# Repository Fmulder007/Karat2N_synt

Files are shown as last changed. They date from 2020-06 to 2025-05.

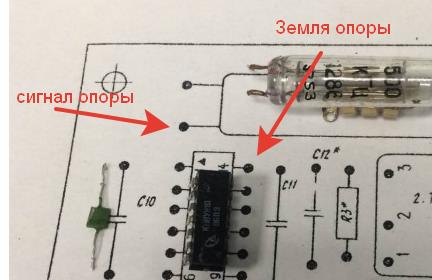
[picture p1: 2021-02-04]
Photo/2021-02-04_23-24-12.jpg

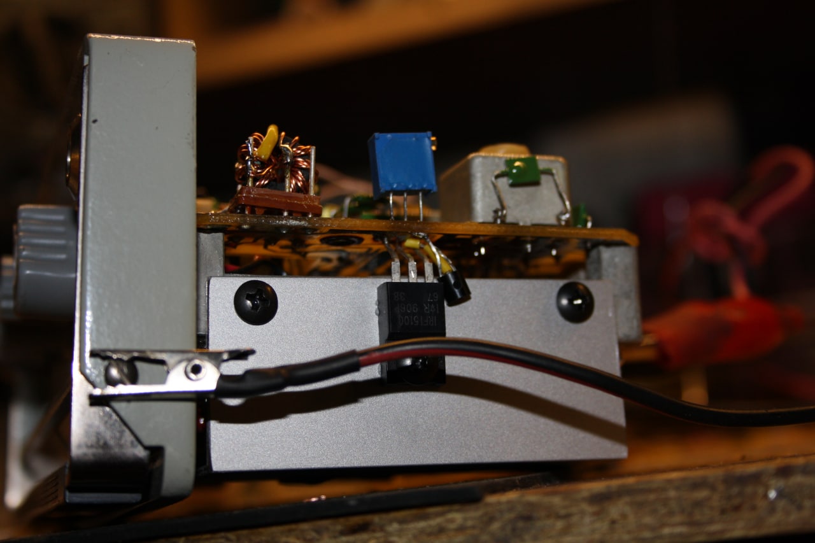
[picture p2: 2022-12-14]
Photo/photo_2022-12-13_17-33-39.jpg

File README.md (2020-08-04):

# Karat2N_synt

Проект модернизации радиостанции Карат-2Н от UD0CAJ.

Функционал:
	Один НЧ любительский диапазон (160,80 или 40 метров)
	
	Шаг настройки 10, 100, 500, 1000 Гц
	
	Нижняя боковая полоса
	
	Синтезатор si5351
	
	Часы DS1307
	
	Память 24C32n
	
	Измерение температуры (датчик DS18B20 имеет тепловой контакт с передней панелью радиостанции)
	
	Сдвиг ПЧ (IF-Shift) на приеме позволяет отстроиться от близкой помехи.
	
	Выходная мощность 2-3 ватта (зависит от диапазона)
	
Видео работы на 40 метрах от Александра Никитенко https://youtu.be/9bqwGd6Wv5c?t=20
Официальный телеграмм канал техподдержки проекта https://t.me/Karat2_sintez
Адрес электронной почты автора fmulder007@yandex.ru

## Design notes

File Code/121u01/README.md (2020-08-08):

# Karat2N_synt
v 121u01
Функционал:
	CLK0 - vfo, CLK1 - lo.
	Один НЧ любительский диапазон (160,80 или 40 метров)
	Шаг настройки 10, 100, 500, 1000 Гц
	Прием=ГПД+ПЧ
	Границы ПЧ от 1 до 25 МГц
	Синтезатор si5351a от UR5FFR
	Часы DS1307 
	Память 24C32n используется для хранения данных
	датчик DS18B20
	Сдвиг ПЧ (IF-Shift) на приеме позволяет отстроиться от близкой помехи.

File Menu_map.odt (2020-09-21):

# Шпаргалка

Радиостанция Карат-2Н

Переделка UD0CAJ

Меню

Меню управления состит из 10 пунктов, которые нумеруются от 0 до 9. Меню разделено на две части: основное меню и инженерное меню. Переход по пунктам внутри каждой части меню осуществляется путём кратковременного нажатия на ручку настройки. Переход между основным и инженерным меню осуществляется путём длительного нажатия на ручку настройки. В основном меню производятся быстрые настройки. В инженерном меню производятся дополнительные настройки, которые не требуется выполнять при обычной работе на радиостанции.

В остальном, методика работы и обслуживания радиостанции аналогична заводскому варианту и производится согласно заводской инструкции по эксплуатации.

Карта меню

Частота опоры Гц

Меню 3

Главный экран

Меню 0

Кратковременное нажатие

Длительное нажатие

Установка минут

Меню 9

Установка часов

Меню 8

Максимальная частота диапазона

Меню 7

If-shift

Меню 2

Шаг настройки Гц

Меню 1

Минимальная частота диапазона

Меню 6

Калибровка кварца синтезатора

Меню 5

Калибровка вольтметра

Меню 4

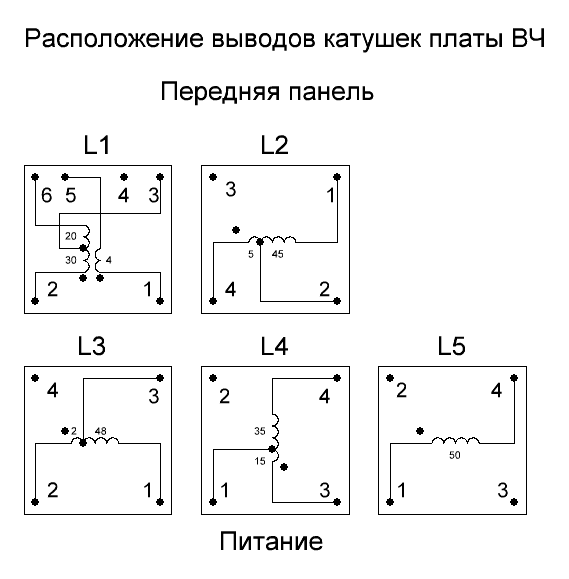
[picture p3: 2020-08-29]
Coils pinout.GIF

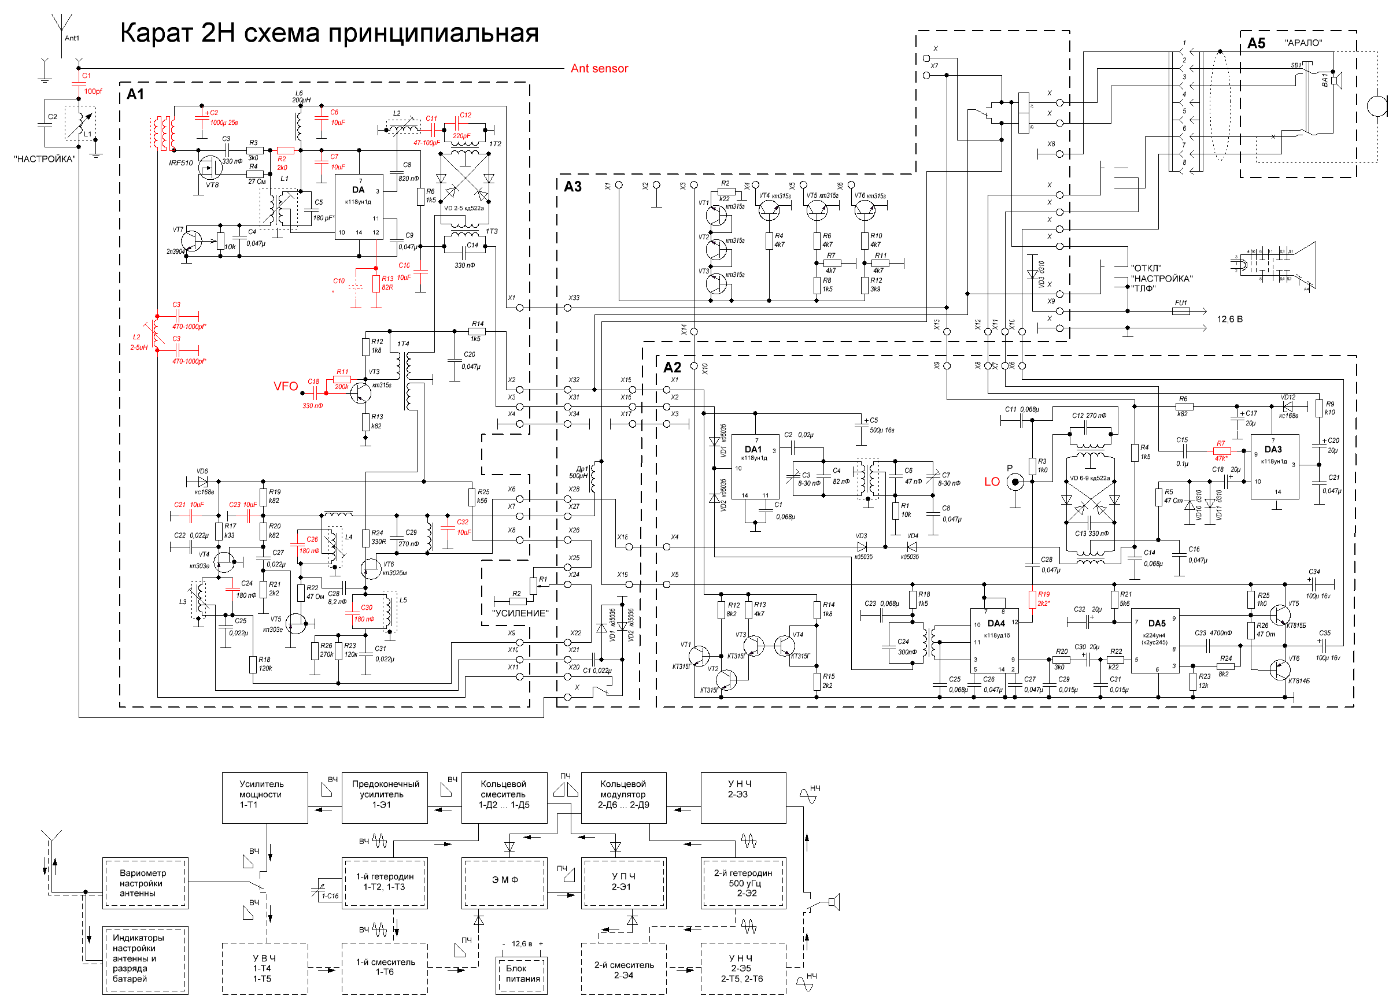
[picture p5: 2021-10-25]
Karat-2N_Full.GIF

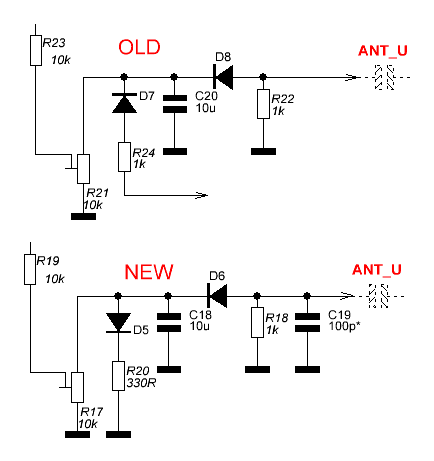
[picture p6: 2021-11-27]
Pokazometr.GIF

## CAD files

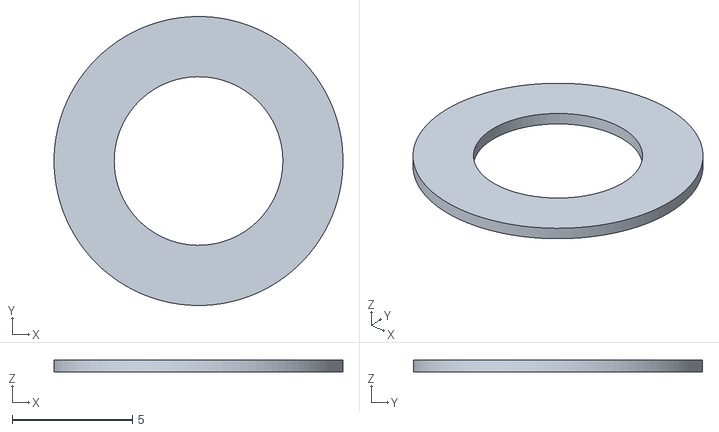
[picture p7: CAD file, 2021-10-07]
3D stuff/Encoder_spacer.stl
12.0 x 12.0 x 0.5

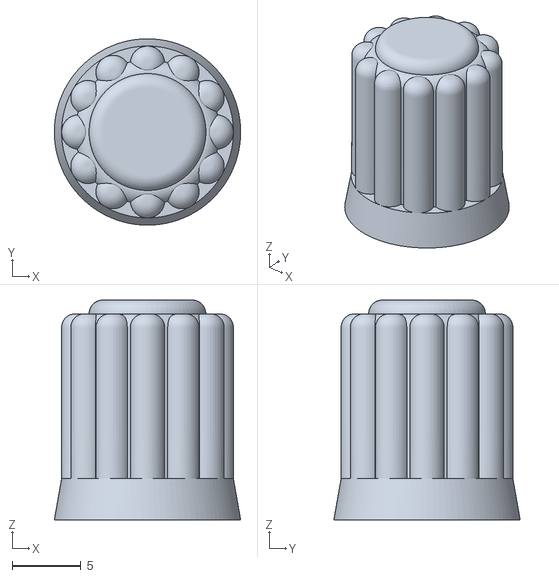
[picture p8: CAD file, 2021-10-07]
3D stuff/encoder_cnob1.stl
13.6 x 13.6 x 16.0

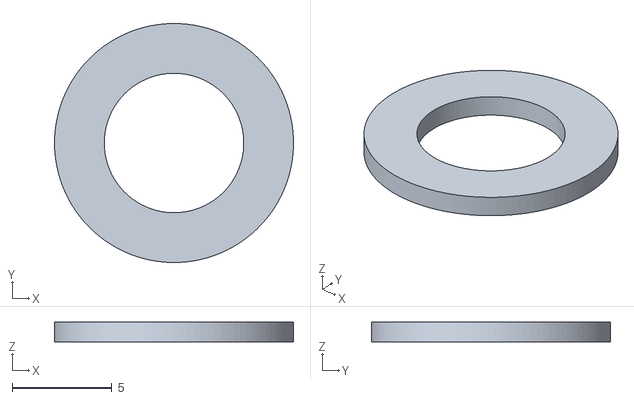
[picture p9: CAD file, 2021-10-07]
3D stuff/Encoder_spacer10.stl
12.0 x 12.0 x 1.00

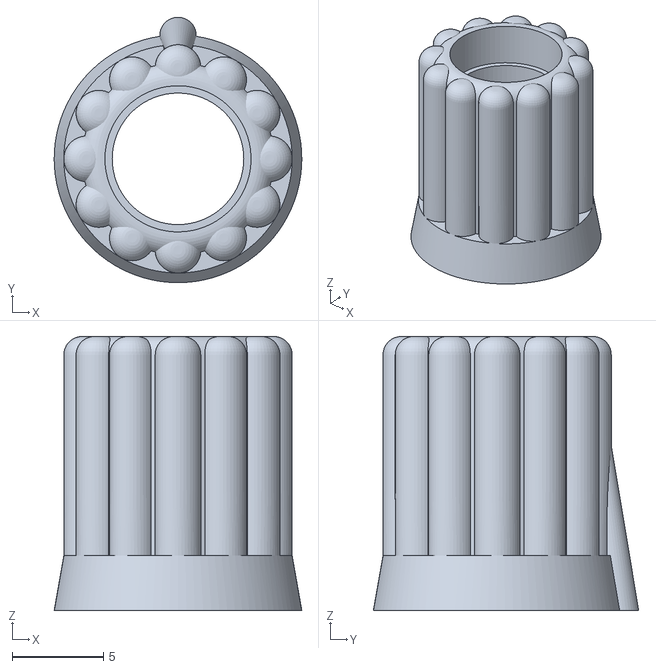
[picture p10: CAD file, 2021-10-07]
3D stuff/volume_cnob3.stl
13.6 x 14.5 x 15.0

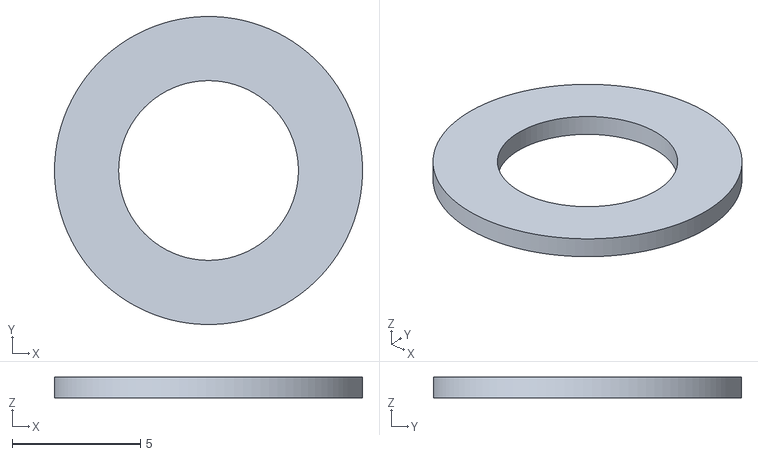
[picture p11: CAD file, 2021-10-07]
3D stuff/Encoder_spacer08.stl
12.0 x 12.0 x 0.8

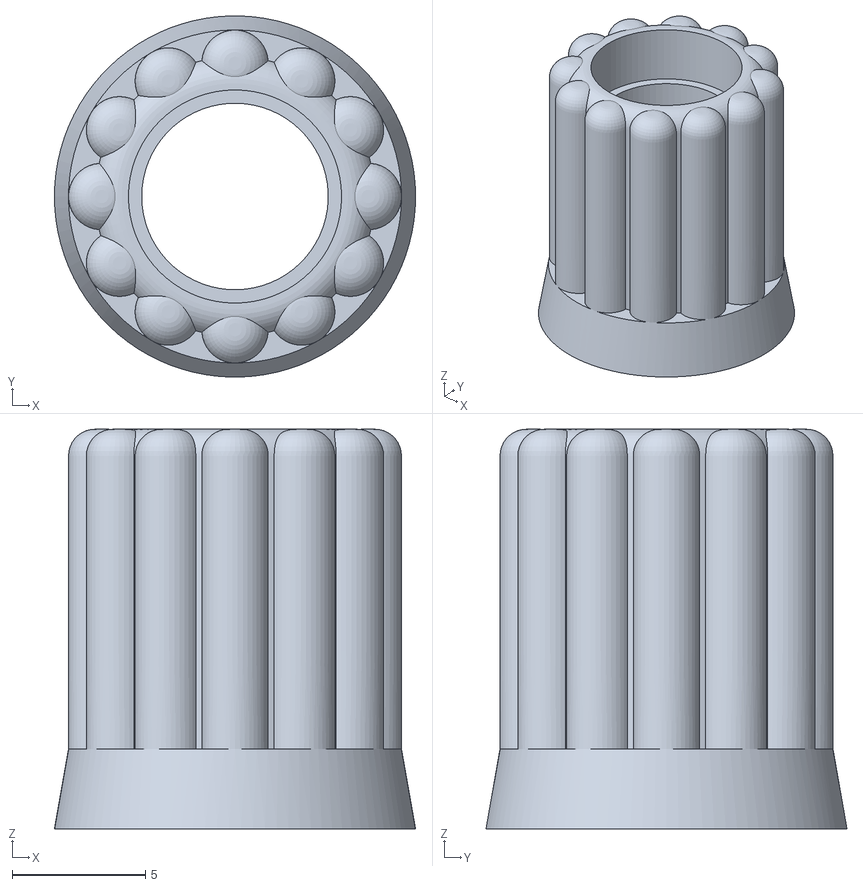
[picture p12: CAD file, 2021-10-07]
3D stuff/volume_cnob1.stl
13.6 x 13.6 x 15.0

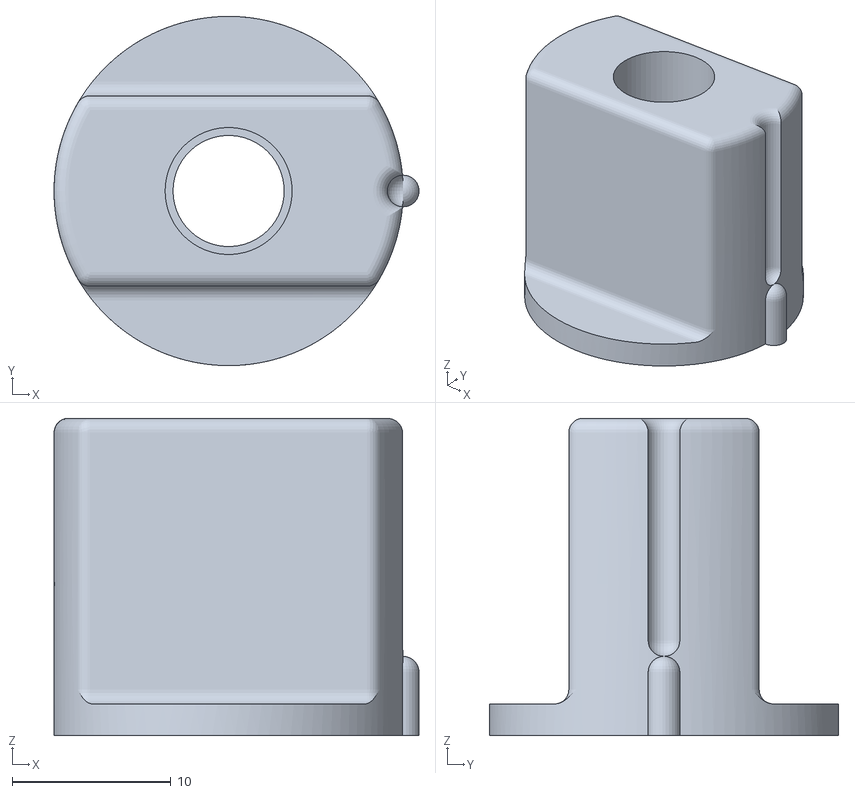
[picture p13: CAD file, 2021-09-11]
3D stuff/Karat-2N_LONG_switch_knob.stl
23.0 x 22.0 x 20.0

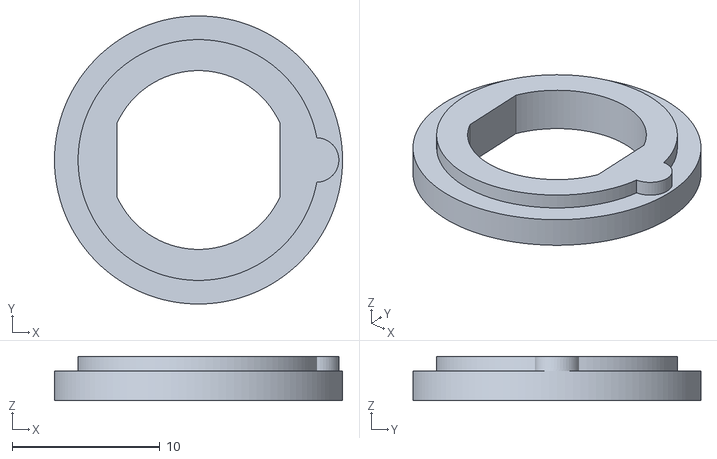
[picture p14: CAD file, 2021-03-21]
3D stuff/Karat-2N_PowerSupply_2.stl
19.5 x 19.5 x 3.00

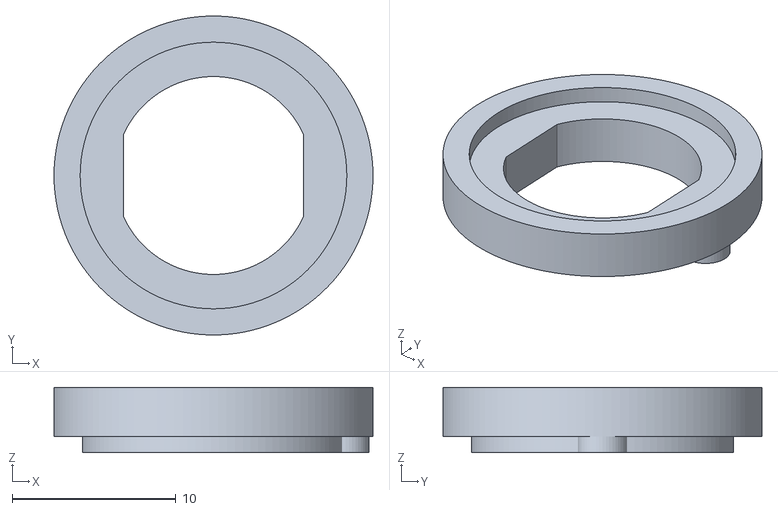
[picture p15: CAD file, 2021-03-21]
3D stuff/Karat-2N_PowerSupply_1.stl
19.5 x 19.5 x 4.00

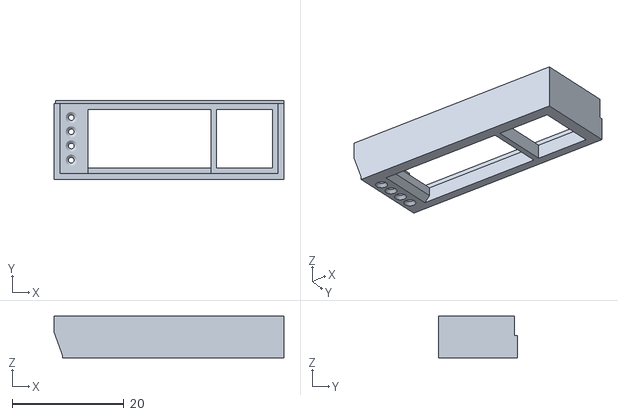
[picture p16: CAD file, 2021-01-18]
3D stuff/OLED0.91_border.stl
41.2 x 14.2 x 7.50

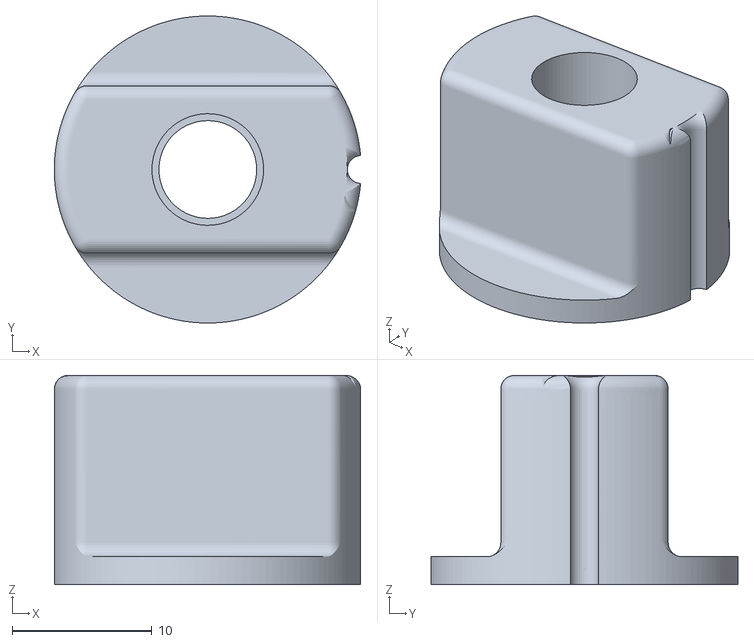
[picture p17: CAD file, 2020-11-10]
3D stuff/Karat-2N_switch_knob.stl
22.0 x 22.0 x 15.0

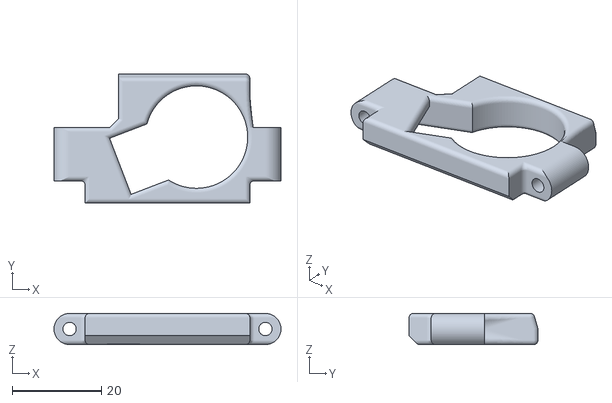
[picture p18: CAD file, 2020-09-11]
3D stuff/Karat2_MIC_Support.stl
51.0 x 29.0 x 7.00

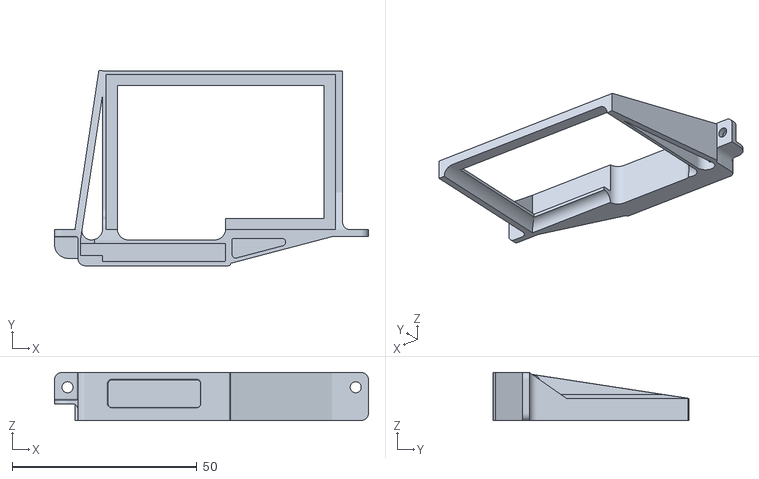
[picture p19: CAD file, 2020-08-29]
3D stuff/Karat_All_Support_1.stl
85.0 x 52.9 x 13.0

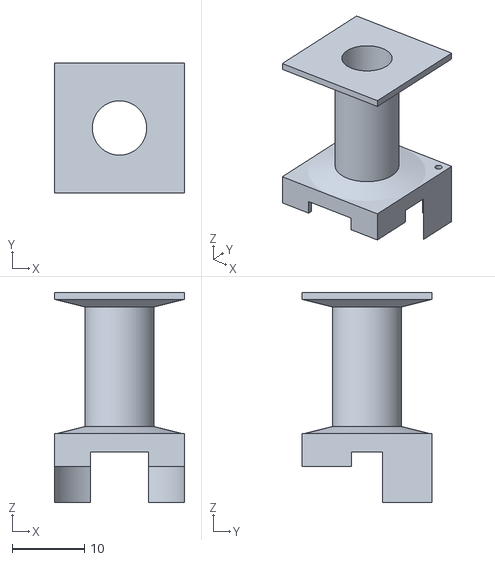
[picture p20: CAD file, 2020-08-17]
3D stuff/Karat-2_Variometr.stl
18.0 x 18.0 x 29.0

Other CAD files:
3D stuff/Karat-2N_switch_knob v1.dwg
3D stuff/Torus.stl
3D stuff/RTC_support.stl
3D stuff/Conduktor.stl
3D stuff/Capacitor_Space.stl
3D stuff/Karat-2N_display_support_2.stl
3D stuff/Karat2_sintez_support1.stl
3D stuff/Karat_Display_Support.stl
3D stuff/Karat_all_Support_1 v6.dwg
3D stuff/Knob1.stl

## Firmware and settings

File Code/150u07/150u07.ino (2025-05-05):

char ver[ ] = "150u07";
/*
   Для однодиапазонной переделки Карат-2Н.
   ВНИМАНИЕ!!! Применять ядро от AlexGyver: https://github.com/AlexGyver/GyverCore
   Добавлен Канальный режим. В нем недоступны "лишние" настройки
   Включение с нажатым кнобом переводит в режим инжменю.
   Добавлен цифровой фильтр для вольтметра
*/

//#define SI_OVERCLOCK 750000000L
#define ENCODER_OPTIMIZE_INTERRUPTS

#define crcmod 7// поправка расчета CRC для НЕ СОВМЕСТИМОСТИ со старыми/другими прошивками

#define SCREEN_WIDTH 128 // OLED display width, in pixels
#define SCREEN_HEIGHT 32 // OLED display height, in pixels
// Declaration for an SSD1306 display connected to I2C (SDA, SCL pins)
#define OLED_RESET     -1 // Reset pin # (or -1 if sharing Arduino reset pin)
#define OLED_I2C_ADRESS 0x3C // Display I2c adress

#define max_number_of_bands	30 // Максимальное количество диапазонов.
#define Si_Xtall_Freq 27000000UL // Частота кварца si5351, Гц.
#define si_cload SI5351_CRYSTAL_LOAD_10PF// 
#define lo_freq 500000UL // Частота опоры 500 КГц.
#define min_hardware_freq 10 // *100KHz Минимальный железный предел частоты диапазона VFO
#define max_hardware_freq 99 // *100KHz Максимальный железный предел частоты диапазона VFO
#define ONE_WIRE_BUS 14 // Порт датчика температуры
#define myEncBtn 4 // Порт нажатия кноба.
#define fwdpin 15 // Порт fwd показометра мощности. А0

#define mybattpin 21 // Порт датчика АКБ
#define txsenspin 17 //Порт датчика ТХ

#define pttpin 6 // PTT
#define dotpin 5 // CW TX dot
#define dashpin 7 // CW TX dash
#define txenpin 9 // TX en out pin
#define rxenpin 8 // RX en out pin
#define tonefreq 500 // Частота тонального сигнала для настройки TX.
#define pttdelay 50 //Задержка выключения PTT

#include "Adafruit_SSD1306.h" // Use version 1.2.7!!!
#include "si5351a.h"
#include "Wire.h"
#include "Encoder.h"
#include "Eeprom24C32_64.h"
#include "OneWire.h"
#include "DallasTemperature.h"
#include "DS1307RTC.h"
#include "GyverTimers.h"

//Общие настройки
struct general_set {
  uint8_t stp = 3; //Начальный шаг настройки.
  uint8_t band_set = 0; // Стартовый диапазон.
  uint8_t number_of_bands_set = 0; // Количество диапазонов.
  bool cmode = false; // Канальный режим.
  int16_t lo_cal_freq_set  = 0; // калибровка опоры 500кГц.
  bool EMF_HI = 0; // Верхний ЭМФ - 1, нижний ЭМФ = 0.
  int16_t Si_Xtall_calFreq_set = 5850; // Начальная частота калибровки кварца, Гц.
  uint8_t batt_cal_set = 208; // Начальная калибровка вольтметра.
  bool reverse_encoder_set = false; //Реверс энкодера.
  uint8_t mem_enc_div = 4; // Делитель импульсов энкодера
  int8_t temp_cal = 0; //Калибровка термометра
  uint8_t cwdelay = 50; // Задержка переключения на прием после CW передачи * 10мсек
  uint8_t cwtone = 70; // Сдвиг частоты CW *10 Гц
  uint8_t cwtype = 0; // 0: BUG Keyer, 1:Paddle Keyer
} general_setting;

#define stp general_setting.stp
#define band general_setting.band_set
#define number_of_bands general_setting.number_of_bands_set
#define cmode general_setting.cmode
#define lo_cal_freq general_setting.lo_cal_freq_set
#define Si_Xtall_calFreq general_setting.Si_Xtall_calFreq_set
#define batt_cal general_setting.batt_cal_set
#define reverse_encoder general_setting.reverse_encoder_set
#define mem_enc_div general_setting.mem_enc_div
#define temp_cal general_setting.temp_cal
#define EMF_HI general_setting.EMF_HI


// Диапазонные настройки
struct band_set {
  bool mode_set = 0; // LSB=0, USB=1.
  uint32_t vfo_freq_set = 3650000UL; // Начальная частота VFO при первом включении.
  uint8_t min_freq_set = 35; // *100KHz Минимальный предел частоты диапазона VFO.
  uint8_t max_freq_set = 38; // *100KHz Максимальный предел частоты диапазона VFO.
} band_setting;
#define mode band_setting.mode_set
#define vfo_freq band_setting.vfo_freq_set
#define min_freq band_setting.min_freq_set
#define max_freq band_setting.max_freq_set

//
//
//

uint8_t menu = 0; //Начальное положение меню.
uint16_t arraystp[] = {1, 10, 50, 100, 500, 1000, 10000}; //шаги настройки * 10 герц.

uint8_t enc_div = 4;

uint16_t fwdpower = 0;

uint8_t mybatt = 0;
int8_t temperature = 0;
uint16_t screenstep = 1000;
uint16_t rawbatt = 0;
bool toneen = false;

long oldPosition  = 0;
bool actencf = false;
bool txen = false;
bool knobup = true;
bool exitmenu = false;
bool reqtemp = false;
bool timesetup = false;
bool actfmenuf = false;

// CW flags
bool cwtxen = false;
bool cwkeydown = false;
bool cwsemitoneen = false;
uint32_t cwkeyreleasetimer = 0;
uint8_t cwkeycount = 0;

// PTT flags
bool ptten = 0;
bool pttdown = 0;
bool state = 0;
uint8_t pttcount = 0;
uint32_t pttreleasetimer = 0;

uint32_t previousdsp = 0;
uint32_t previoustemp = 0;
uint32_t previoustime = 0;
uint32_t knobMillis = 0;
uint32_t actenc = 0;



static Eeprom24C32_64 AT24C32(0x50);
Si5351 si;
Encoder myEnc(2, 3); //порты подключения енкодера.
Adafruit_SSD1306 display(SCREEN_WIDTH, SCREEN_HEIGHT, &Wire, OLED_RESET);
OneWire oneWire(ONE_WIRE_BUS);
DallasTemperature sensors(&oneWire);
tmElements_t tm;


void setup() {
  //PTT control setup
  pinMode (pttpin, INPUT); // PTT pin input
  pinMode (txenpin, OUTPUT); // TX control pin output
  pinMode (rxenpin, OUTPUT); // RX control pin output
  digitalWrite (pttpin, LOW); // PTT pin pullup
  digitalWrite (txenpin, LOW); // TX control pin pullup
  digitalWrite (rxenpin, LOW); // RX control pin pullup

  //CW pin`s setup
  pinMode (dotpin, INPUT);      //CW dotpin input
  pinMode (dashpin, INPUT);         //CW dashpin input
  digitalWrite (dotpin, LOW);      // CW dotpin pin pullup Disable
  digitalWrite (dashpin, LOW);     // CW dashpin pin pullup Disable
  pinMode (10, OUTPUT);      // настроить пин 10 как выход для тональника

  // other pin`s setup
  pinMode(myEncBtn, INPUT);
  pinMode(fwdpin, INPUT);
  digitalWrite(myEncBtn, HIGH);
  analogReference(INTERNAL);
  //=====================//
  display.begin(SSD1306_SWITCHCAPVCC, OLED_I2C_ADRESS);
  display.clearDisplay();
  display.display();
  sensors.begin();
  memread();
  enc_div = mem_enc_div;
  si5351init();
  si5351correction();
  vfosetup();
  battmeter();
  powermeter();
  tempsensor ();
  timenow ();
  if (!digitalRead(myEncBtn)) menu = 100;
  versionprint ();
  mainscreen();

}

void loop() { // Главный цикл
  pttsensor();
  cw();
  rxtxcontrol();
  //=====//
  pushknob();
  if (!cmode) readencoder(); //Если не в канальном режиме - считать енкодер
  if (cmode && menu) readencoder(); //Если в канальном режиме и не на главном экране - считать енкодер
  txsensor();
  battmeter();
  if (!menu) {
    if (txen) screenstep = 50;
    else screenstep = 1000;
    if (millis() - previousdsp > screenstep) {
      storetomem();
      powermeter();
      tempsensor();
      timenow();
      mainscreen();
      previousdsp = millis();
    }
  }
}

void timenow () {
  if (timesetup) {
    tm.Second = 0;
    RTC.write(tm);
    timesetup = false;
  }
  else {
    if (millis() - previoustime > 1000 || !previoustime) {
      previoustime = millis();
      if (!RTC.read(tm)) {
        if (RTC.chipPresent()) {
          tm.Hour = 0;  tm.Minute = 0; tm.Second = 0;
          RTC.write(tm);
        }
      }
    }
  }
}

void tempsensor () { //Измерение температуры
  if (millis() - previoustemp > 5000 && !reqtemp) {
    sensors.setWaitForConversion(false);
    sensors.requestTemperatures();
    sensors.setWaitForConversion(true);
    reqtemp = true;
  }
  if (millis() - previoustemp > 8000 && reqtemp) {
    temperature = (int8_t)(0.5 + sensors.getTempCByIndex(0));
    temperature = temperature + temp_cal;
    previoustemp = millis();
    reqtemp = false;
  }
}

void txsensor () {
  bool txsens = digitalRead(txsenspin);
  //Если радио на приеме и нажали ТХ то txen = true
  if (txsens && !txen) {
    txen = true;
    mainscreen();
  }
  //Если радио на передаче и отпустили ТХ то txen = false
  if (!txsens && txen) {
    txen = false;
    mainscreen();
  }
}

void pushknob () {  // Обработка нажатия на кноб

  bool knobdown = digitalRead(myEncBtn);   //Читаем состояние кноба
  if (!knobdown && knobup) {   //Если кноб был отпущен, но нажат сейчас
    knobup = false;   // отмечаем флаг что нажат
    knobMillis = millis();  // запускаем таймер для антидребезга
  }

  if (knobdown && !knobup) { //Если кноб нажат
    knobup = true; // отмечаем флаг что кноб отпущен
    long knobupmillis = millis();
    if (knobupmillis - knobMillis >= 1000) { //Если длительное нажатие
      if (menu == 0) {
        if (cmode) menu = 23;
        else menu = 20;// Если долгое нажатие на главном экране, то перейти в юзерменю
      }
      else if (menu != 0) menu = 0; // Если долгое нажатие не на главном экране, то перейти на главный экран
    }

    if (knobupmillis - knobMillis < 1000 && knobupmillis - knobMillis > 100) { //Если кноб отпущен и был нажат и времени от таймера прошло 100Мс
      if (menu < 4 && menu > 0 && actfmenuf) //Если 0<меню<4 и крутили енкодер в быстром меню, то выйти на главный экран
      {
        actfmenuf = false;
        menu = 0;
      }
      else {
        menu ++; //Переходим на меню дальше
        if (menu == 4) menu = 0; //Если меню 5 выйти на главный экран
        if (menu > 28 && menu < 100) menu = 20; //Если меню > 30 но < 100 перейти на меню 20
        if (menu > 105) menu = 100; //Если меню больше 105 перейти на меню 100
      }
      if (!number_of_bands && (menu == 1 || menu == 100)) menu++; // Если каналы не настроены, то нет меню 1 и 100
      if (cmode && number_of_bands) {                             //Если в канальном режиме, то пропускать меню 2,3,20,21,22,25,26
        switch (menu) {
          case 2:
          case 3: menu = 0;
            break;
          case 20:
          case 21:
          case 22:
          case 25:
          case 26: menu = 23;
          case 27: menu = 23;
          case 28: menu = 23;
            break;
        }
      }
    }
    mainscreen();
  }
}

void storetomem() { // Если крутили енкодер, то через 10 секунд все сохранить

  if ((millis() - actenc > 10000UL) && actencf) {
    actenc = millis();
    actencf = false;
    memwrite ();
  }
}

void readencoder() { // работа с енкодером
  long newPosition;
  newPosition = myEnc.read() / enc_div;
  if (reverse_encoder) newPosition *= (-1);
  if (newPosition != oldPosition && digitalRead(myEncBtn)) { // ЕСЛИ КРУТИЛИ энкодер

    if (menu > 0 && menu < 5) actfmenuf = true; // Если крутили энкодер в быстром меню - флаг вверх!
    switch (menu) {

      case 0: //Основная настройка частоты
        if (newPosition > oldPosition && vfo_freq <= max_freq * 100000UL) {
          if (vfo_freq % (arraystp[stp] * 10UL)) {
            vfo_freq = vfo_freq + (arraystp[stp] * 10UL) - (vfo_freq % (arraystp[stp] * 10UL));
          }
          else {
            vfo_freq = vfo_freq + (arraystp[stp] * 10UL);
          }
        }
        if (newPosition < oldPosition && vfo_freq >= min_freq * 100000UL) {
          if (vfo_freq % (arraystp[stp] * 10UL)) {
            vfo_freq = vfo_freq - (vfo_freq % (arraystp[stp] * 10UL));
          }
          else {
            vfo_freq = vfo_freq - (arraystp[stp] * 10UL);
          }
        }
        if (vfo_freq < min_freq * 100000UL) vfo_freq = min_freq * 100000UL;
        if (vfo_freq > max_freq * 100000UL) vfo_freq = max_freq * 100000UL;
        vfosetup();
        break;

      case 1: //Переключение каналов
        if (newPosition > oldPosition && band < number_of_bands) band++;
        if (newPosition < oldPosition && band > 0) band--;
        //if (band > number_of_bands) band = number_of_bands;
        band = constrain(band, 0, number_of_bands);
        band_memread();
        vfosetup();
        break;

      case 2: //Настройка ШАГА настройки
        if (newPosition > oldPosition && stp < (sizeof(arraystp) / sizeof(arraystp[0]) - 1)) stp++;
        if (newPosition < oldPosition && stp > 0) stp--;
        //if (stp < 10) stp = 10;
        if (stp > (sizeof(arraystp) / sizeof(arraystp[0]) - 1)) stp = (sizeof(arraystp) / sizeof(arraystp[0]) - 1);
        break;

      case 3: //Переключение LSB|USB.
        mode = !mode;
        vfosetup();
        break;

      case 20: //Настройка min_freq
        if (newPosition > oldPosition && min_freq <= max_hardware_freq) min_freq++;
        if (newPosition < oldPosition && min_freq >= min_hardware_freq) min_freq--;
        min_freq = constrain(min_freq, min_hardware_freq, max_freq - 1);
        break;

      case 21: //Настройка maxfreq
        if (newPosition > oldPosition && max_freq <= max_hardware_freq) max_freq++;
        if (newPosition < oldPosition && max_freq >= min_hardware_freq) max_freq--;
        max_freq = constrain(max_freq, min_freq + 1, max_hardware_freq);
        break;

      case 22: // Настройка количества каналов
        if (newPosition > oldPosition && number_of_bands < max_number_of_bands) number_of_bands++;
        if (newPosition < oldPosition && number_of_bands > 0) number_of_bands--;
        if (number_of_bands > max_number_of_bands) number_of_bands = max_number_of_bands;
        if (band > number_of_bands) band = number_of_bands;
        break;

      case 23: //Настройка Часов
        if (newPosition > oldPosition && tm.Hour < 24) tm.Hour++;
        if (newPosition < oldPosition && tm.Hour > 0) tm.Hour--;
        if (tm.Hour > 23) tm.Hour = 23;
        timesetup = true;
        break;

      case 24: //Настройка Минут
        if (newPosition > oldPosition && tm.Minute < 60) tm.Minute++;
        if (newPosition < oldPosition && tm.Minute > 0) tm.Minute--;
        if (tm.Minute > 59) tm.Minute = 59;
        timesetup = true;
        break;

      case 25: // Настройка CW-Delay
        if (newPosition > oldPosition && general_setting.cwdelay < 255) general_setting.cwdelay++;
        if (newPosition < oldPosition && general_setting.cwdelay > 1) general_setting.cwdelay--;
        general_setting.cwdelay = constrain(general_setting.cwdelay, 10, 255);
        break;

      case 26: // Настройка CW-Tone
        if (newPosition > oldPosition && general_setting.cwtone < 255) general_setting.cwtone++;
        if (newPosition < oldPosition && general_setting.cwtone > 1) general_setting.cwtone--;
        general_setting.cwtone = constrain(general_setting.cwtone, 10, 255);
        break;

      case 27: // Настройка делителя импульсов энкодера
        if (newPosition > oldPosition && mem_enc_div < 255) mem_enc_div++;
        if (newPosition < oldPosition && mem_enc_div > 1) mem_enc_div--;
        mem_enc_div = constrain(mem_enc_div, 1, 255);
        break;

      case 28: //Инверсия энкодера.
        if (reverse_encoder) {
          reverse_encoder = false;
        }
        else {
          reverse_encoder = true;
        }
        newPosition *= (-1);
        break;

      case 100: //Канальный режим.
        cmode = !cmode;
        break;

      case 101: //Настройка калибровки по питанию
        if (newPosition > oldPosition && batt_cal <= 254) batt_cal++;
        if (newPosition < oldPosition && batt_cal >= 100) batt_cal--;
        if (batt_cal > 254) batt_cal = 254;
        if (batt_cal < 100) batt_cal = 100;
        break;

      case 102: //Калибровка термодатчика
        if (newPosition > oldPosition && temp_cal <= 30) temp_cal++;
        if (newPosition < oldPosition && temp_cal >= - 30) temp_cal--;
        temp_cal = constrain(temp_cal, -30, 30);
        break;

      case 103: //Частота кварца синтезатора
        if (newPosition > oldPosition && Si_Xtall_calFreq <= 30000) Si_Xtall_calFreq += arraystp[stp];
        if (newPosition < oldPosition && Si_Xtall_calFreq >= - 30000) Si_Xtall_calFreq -= arraystp[stp];
        Si_Xtall_calFreq = constrain(Si_Xtall_calFreq, -30000, 30000);
        si5351correction();
        vfosetup();
        break;

      case 104: //1пч
        if (newPosition > oldPosition) lo_cal_freq += arraystp[stp];
        if (newPosition < oldPosition) lo_cal_freq -= arraystp[stp];
        lo_cal_freq = constrain(lo_cal_freq, (-1000), 1000);
        vfosetup();
        break;

      case 105: //Верхний ЭМФ.
        EMF_HI = !EMF_HI;
        break;


    }
    actenc = millis();
    actencf = true;
    mainscreen();
    oldPosition = newPosition;
  }
}

void powermeter () { // Измеритель уровня выхода
  /*
   * filt = (A * filt + B * signal) >> k;
   * Коэффициенты у этого фильтра выбираются следующим образом:    
   * k = 1, 2, 3…   
   * A + B = 2^k
   * Чем больше А, тем плавнее фильтр (отношение A/B)
   * Чем больше k, тем более плавным можно сделать фильтр. Но больше 5 уже нет смысла, т.к. A=31, B=1 уже 
   * очень плавно, а при увеличении может переполниться int и придётся использовать 32-х битные типы данных.
   * Результат умножения не должен выходить за int, иначе придётся преобразовывать к long
   * Более подробно о выборе коэффициентов читайте в статье, ссылка выше
   * Особенность: если “ошибка” сигнала (signal – filter) меньше 2^k – фильтрованное 
   * значение меняться не будет. Для повышения “разрешения” фильтра можно домножить (или сдвинуть) 
   * переменную фильтра, то есть фильтровать в бОльших величинах
  */
  fwdpower = (12 * fwdpower + 4 * (analogRead(fwdpin))) >> 4;
}

void battmeter () { // Измеритель напряжения питания
  //rawbatt = analogRead(mybattpin);
  rawbatt = (14 * rawbatt + 2 * (analogRead(mybattpin))) >> 4; // Крутой фильтр для усреднения показаний вольтметра!!!
  mybatt = map(rawbatt, 0, 1023, 0, batt_cal);
}
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

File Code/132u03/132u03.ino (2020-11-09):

char ver[ ] = "141y02";

#define SI_OVERCLOCK 750000000L
#define ENCODER_OPTIMIZE_INTERRUPTS

#define max_number_of_bands	99 // Максимальное оличество диапазонов.
#define Si_Xtall_Freq 27000000UL // Частота кварца si5351, Гц.
#define si_cload SI5351_CRYSTAL_LOAD_8PF// 
#define lo_max_freq 550000UL // Максимальная частота опоры, Гц.
#define lo_min_freq 450000UL // Минимальная частота опоры, Гц.
#define min_hardware_freq 10 // *100KHz Минимальный железный предел частоты диапазона VFO
#define max_hardware_freq 99 // *100KHz Максимальный железный предел частоты диапазона VFO
#define ifstep 50 // Шаг IF-Shift, Гц
#define ONE_WIRE_BUS 10 // Порт датчика температуры
#define myEncBtn 4 // Порт нажатия кноба.
#define mypowerpin 16 // Порт показометра мощности. А0
#define mybattpin 14 // Порт датчика АКБ А1
#define txpin 17 //Порт датчика ТХ.


#include "Adafruit_SSD1306.h" // Use version 1.2.7!!!
#include "si5351a.h"
#include "Wire.h"
#include "Encoder.h"
#include "Eeprom24C32_64.h"
#include "OneWire.h"
#include "DallasTemperature.h"
#include "DS1307RTC.h"

//Общие настройки
struct general_set {
  byte stp_set = 3; //Начальный шаг настройки.
  byte band_set = 0; // Стартовый диапазон.
  byte number_of_bands_set = 10; // Количество диапазонов.
  unsigned long lo_lsb_freq_set = 496203UL; // Начальная частота опоры LSB при первом включении.
  unsigned long lo_usb_freq_set  =  500000UL; // Начальная частота опоры USB при первом включении.
  int Si_Xtall_calFreq_set = 5000; // Начальная частота калибровки кварца, Гц.
  int ifshift_set = 0;
  byte batt_cal_set = 212; // Начальная калибровка вольтметра
} general_setting;

#define stp general_setting.stp_set
#define band general_setting.band_set
#define number_of_bands general_setting.number_of_bands_set
#define lo_lsb_freq general_setting.lo_lsb_freq_set
#define lo_usb_freq general_setting.lo_usb_freq_set
#define Si_Xtall_calFreq general_setting.Si_Xtall_calFreq_set
#define ifshift general_setting.ifshift_set
#define batt_cal general_setting.batt_cal_set

// Диапазонные настройки
struct band_set {
  boolean mode_set = 0; // LSB=0, USB=1.
  unsigned long vfo_freq_set = 7100000UL; // Начальная частота VFO при первом включении.
  byte min_freq_set = 15; // *100KHz Минимальный предел частоты диапазона VFO.
  byte max_freq_set = 80; // *100KHz Максимальный предел частоты диапазона VFO.
} band_setting;
#define mode band_setting.mode_set
#define vfo_freq band_setting.vfo_freq_set
#define min_freq band_setting.min_freq_set
#define max_freq band_setting.max_freq_set

//
//
//

byte menu = 0; //Начальное положение меню.
unsigned int arraystp[] = {1, 10, 50, 100, 1000}; //шаги настройки * 10 герц.

byte mypower;
byte mybatt;
byte temperature;
int screenstep = 1000;

long oldPosition  = 0;
boolean actencf = false;
boolean txen = false;
int RXifshift = 0;
boolean knobup = true;
boolean exitmenu = false;
boolean reqtemp = false;
boolean timesetup = false;
boolean actfmenuf = false;

// unsigned long previousMillis = 0;
unsigned long previousdsp = 0;
unsigned long previoustemp = 0;
unsigned long previoustime = 0;
unsigned long knobMillis = 0;
unsigned long actenc = 0;


static Eeprom24C32_64 AT24C32(0x50);
Si5351 si;
Encoder myEnc(3, 2); //порты подключения енкодера.
Adafruit_SSD1306 display(4);
OneWire oneWire(ONE_WIRE_BUS);
DallasTemperature sensors(&oneWire);
tmElements_t tm;


void setup() {
  Serial.begin(57600);
  pinMode(myEncBtn, INPUT);
  pinMode(mypowerpin, INPUT);
  digitalWrite(myEncBtn, HIGH);
  analogReference(INTERNAL);
  display.begin(SSD1306_SWITCHCAPVCC, 0x3C);
  display.clearDisplay();
  display.display();
  sensors.begin();
  memread();
  si5351init();
  si5351correction();
  vfosetup();
  battmeter();
  powermeter();
  tempsensor ();
  timenow ();
  versionprint ();
  mainscreen();
}

void loop() { // Главный цикл
  pushknob ();
  readencoder();
  txsensor ();
  if (!menu) {
    if (txen) screenstep = 100;
    else screenstep = 1000;
    if (millis() - previousdsp > screenstep) {
      storetomem();
      battmeter();
      powermeter();
      tempsensor ();
      timenow ();
      mainscreen();
      previousdsp = millis();
    }
  }
}

void timenow () {
  if (timesetup) {
    tm.Second = 0;
    RTC.write(tm);
    timesetup = false;
  }
  else {
    if (millis() - previoustime > 1000 || !previoustime) {
      previoustime = millis();
      if (!RTC.read(tm)) {
        if (RTC.chipPresent()) {
          tm.Hour = 0;  tm.Minute = 0; tm.Second = 0;
          RTC.write(tm);
        }
      }
    }
  }
}

void tempsensor () {
  if (millis() - previoustemp > 5000 && !reqtemp) {
    sensors.setWaitForConversion(false);
    sensors.requestTemperatures();
    sensors.setWaitForConversion(true);
    reqtemp = true;
  }
  if (millis() - previoustemp > 8000 && reqtemp) {
    temperature = (byte)(0.5 + sensors.getTempCByIndex(0));
    previoustemp = millis();
    reqtemp = false;
  }
}

void txsensor () {
  boolean txsens = digitalRead(txpin);
  //Если радио на приеме и нажали ТХ то обнулить IF-SHIFT
  if (txsens && !txen) {
    txen = true;
    RXifshift = 0;
    vfosetup();
  }
  //Если радио на передаче и отпустили ТХ то прописать IF-SHIFT
  if (!txsens && txen) {
    txen = false;
    RXifshift = ifshift;
    vfosetup();
    mainscreen();
  }
  //Если радио на приеме и НЕ нажали ТХ и RXifshift не равно ifshift то прописать IF-SHIFT
  if (!txsens && !txen && RXifshift != ifshift) {
    txen = false;
    RXifshift = ifshift;
    vfosetup();
  }
}

void pushknob () {  // Обработка нажатия на кноб

  boolean knobdown = digitalRead(myEncBtn);   //Читаем состояние кноба
  if (!knobdown && knobup) {   //Если кноб был отпущен, но нажат сейчас
    knobup = false;   // отмечаем флаг что нажат
    knobMillis = millis();  // запускаем таймер для антидребезга
  }

  if (knobdown && !knobup) { //Если кноб нажат
    knobup = true; // отмечаем флаг что кноб отпущен
    long knobupmillis = millis();
    if (knobupmillis - knobMillis >= 1000) { //Если длительное нажатие
      if (menu == 0) menu = 5;
      else if (menu != 0) menu = 0;
    }

    if (knobupmillis - knobMillis < 1000 && knobupmillis - knobMillis > 100) { //Если кноб отпущен и был нажат и времени от таймера прошло 100Мс
      if (menu < 5 && menu > 0 && actfmenuf) { //Если 0<меню<5 и крутили енкодер в быстром меню, то выйти на главный экран
        actfmenuf = false;
        menu = 0;
      }
      else {
        menu ++; //Переходим на меню дальше
        if (menu == 5) menu = 0; //Если меню 5 выйти на главный экран
        if (menu > 13) menu = 5; //Если меню больше 14 перейти на меню 5
      }
      if (!number_of_bands && menu == 1) menu++;
    }

    mainscreen();
  }
}

void storetomem() { // Если крутили енкодер, то через 10 секунд все сохранить

  if ((millis() - actenc > 10000UL) && actencf) {
    actenc = millis();
    actencf = false;
    memwrite ();
  }
}
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

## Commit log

2020-05-18 Display freq Up to 10 Hz.
2020-05-22 Update schematic
2020-06-16 sync fm
    [Sintez1_Ф1_верх.gbr_iso.DXF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]
2020-08-03 add 500hz
2020-08-07 new siboard
    [si5351_Ф1_верх.gbr]
2020-08-13 upd
    Corrected CRC check
    Adding RTC support 3D model
    [Conduktor.stl, RTC_support.stl]
2020-08-13 ver 122u02 added
    [RTC_support.stl]
2020-08-17 122u02 upd
    27MHz sixtall
    8pf int load cap
    CLK2 out for IF freq
    Good variant
    [Karat-2_Variometr.stl, Karat_All_Support_1.stl, Torus.stl]
2021-02-05 135u02 added
    Added tone generator function for ANT tune on 12 pin.
    For tone out choice menu NOT 0 and press PTT
